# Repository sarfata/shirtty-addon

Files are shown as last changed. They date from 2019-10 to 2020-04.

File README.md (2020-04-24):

# shIRtty

A CircuitPython compatible, SAMD21 shitty addon with IR transmit/receive and RGB
LED.

## Bugs / Issues on v1.

**IMPORTANT** To make things more shitty the SAO header is upside down on the
badge. You will need a shitty inverser (included in this repo) or to put the
addon upside down. 

This is the pinout when looking at the face of the badge. Note that VCC is
bottom right (bottom left if you are looking at the connector).

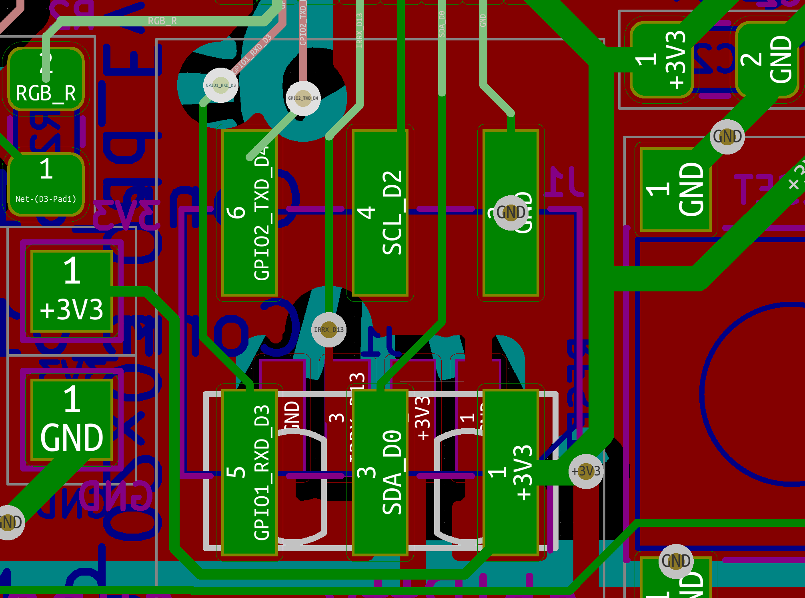
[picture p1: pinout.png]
pinout


### TODOs

- [ ] the SAO connector is upside down
- [ ] we need more capacitance on the +3V line otherwise we brown out when
    transmitting IR
- [ ] replace the very unreliable PCB usb connector by a micro usb connector
- [ ] make the reset button smaller so we can actually fit a SMD 6 pin SAO
    shrouded connector
- [ ] expose some GPIOs? 

## Micropython variant

### Build

Look at the readme in ports/atmel-samd.

```
# needed so gettext/msgfmt is available during build
export PATH="/usr/local/opt/gettext/bin:$PATH"

git clone git@github.com:adafruit/circuitpython.git
git submodule update --init --recursive
make -C mpy-cross

cd ports/atmel-samd

make BOARD=trinket_m0
(stopped there something funky going on where echo toto |xargs arm-none-eabi-gcc does not work)

```

## Bootloader

Some reference:

- https://forums.adafruit.com/viewtopic.php?f=57&t=142170&sid=a506885e77155bd9e062bbbab892efa3&start=15
- https://learn.adafruit.com/how-to-program-samd-bootloaders/itsybitsy-m0-m4-wiring

TODO:

- [x] Change the led configuration so they work on the RGB led we have on our board

### Build the bootloader

We only add two files from the adafruit version of the uf2 bootloader:

```
git clone git@github.com:adafruit/uf2-samdx1.git
```

`~/work/uf2-samdx1/boards/shirtty/board.mk`

```
CHIP_FAMILY = samd21
CHIP_VARIANT = SAMD21E18A
```

`uf2-samdx1/boards/shirtty/board_config.h`

```
#ifndef BOARD_CONFIG_H
#define BOARD_CONFIG_H

#define CRYSTALLESS 1

#define VENDOR_NAME "@sarfata"
#define PRODUCT_NAME "shIRtty"
#define VOLUME_LABEL "shIRtty"
#define INDEX_URL "https://github.com/sarfata/shirtty-addon"
#define BOARD_ID "shIRtty"

#define USB_VID 0x239A
#define USB_PID 0x001E

#define LED_PIN PIN_PA14

#endif
```

Then build with:

```
$ make BOARD=shirtty
```

I got an error at the end on a selfmain.c used for self update. #aintgottimeforthat - does not matter because the elf for the bootloader was built properly earlier.

### Using the Black Magic Probe

Connect:

- GND of the board to GND of BMP (use the SAO header)
- VCC of the board to VCC of BMP (use the SAO header)
- SWC/SWD/RST on the board to BMP (RST is optional - see below)

```
$ arm-none-eabi-gdb build/shirtty/bootloader-shirtty-v3.7.0-54-g63b4c6f.elf
(gdb) target extended-remote /dev/cu.usbmodem7AB17EC11

# If you need the black magic to provide power:
(gdb) monitor tpwr enable

(gdb) monitor swdp_scan
Target voltage: 3.3V
Available Targets:
No. Att Driver
 1      Atmel SAMD21E18A (rev D)
(gdb) attach 1

# if the bootloader is protected
(gdb) monitor unlock_bootprot

(gdb) load
(gdb) compare-sections

# if you want the new bootloader protected
(gdb) monitor lock_bootprot
```

Note: if you don't connect the RST line, you have to press reset after applying power, before running the `monitor` command. If the RST line is connected that is not needed.

### Unprotecting / Protecting the bootloader

First I had to update the firmware on my black magic probe (I had 1.6.1), I followed readme recommendations and installed daily build.

Version before:

    Black Magic Probe (Firmware 04d9749) (Hardware Version 3)

Upgrade with:

    sudo dfu-util -d 1d50:6018,:6017 -s 0x08002000:leave -D ~/Downloads/blackmagic-native.bin

Version after:

    Black Magic Probe (Firmware 04d9749) (Hardware Version 3)

Then the commands monitor unlock_bootprot becomes available.

Note: commands above do not work on the trinket m0 because the bootloader is protected. They should work on a fresh samd21e18 though.

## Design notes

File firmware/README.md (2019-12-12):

### How to setup a fresh ShIRtty.

1. Plug it into USB.
2. Copy all the files in `firmware/main` into the `CIRCUITPY` USB device.

### How to change the ShIRtty code.

1. Plug it into USB.
2. Open mu-editor
3. Load the code from `CIRCUITPY` USB device (`code.py` is the main file)
4. Save! (mu-editor should auto-update)

Pro-Tip: open the "Serial" window for a REPL and output.

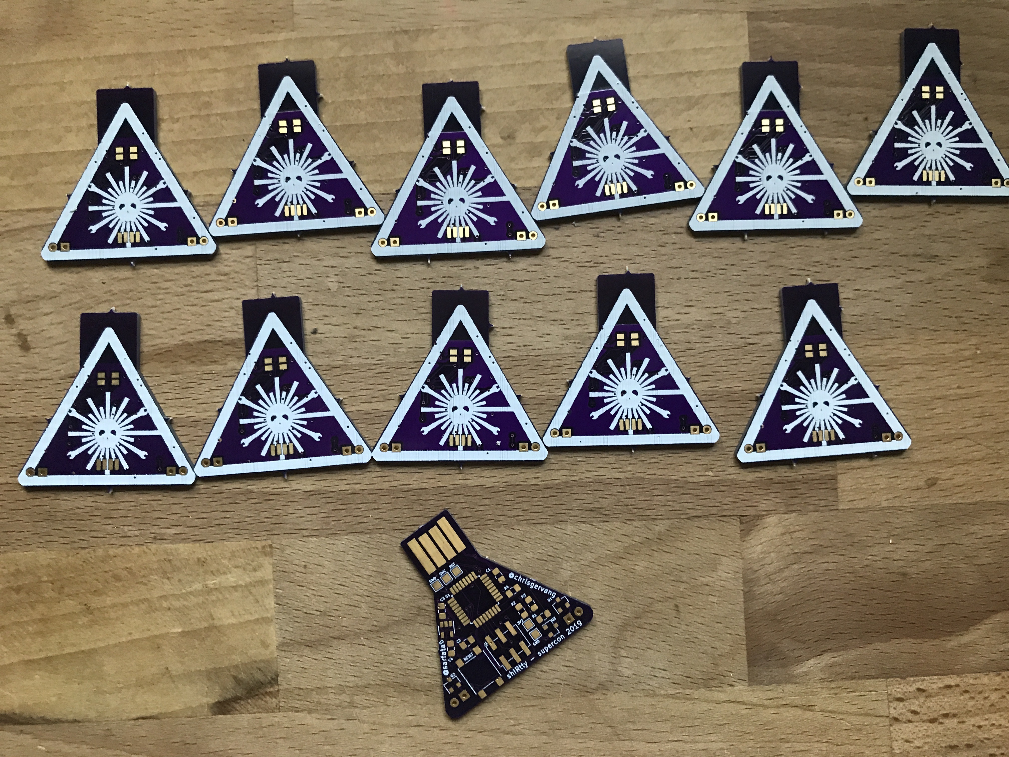
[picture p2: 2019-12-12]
photo.jpeg

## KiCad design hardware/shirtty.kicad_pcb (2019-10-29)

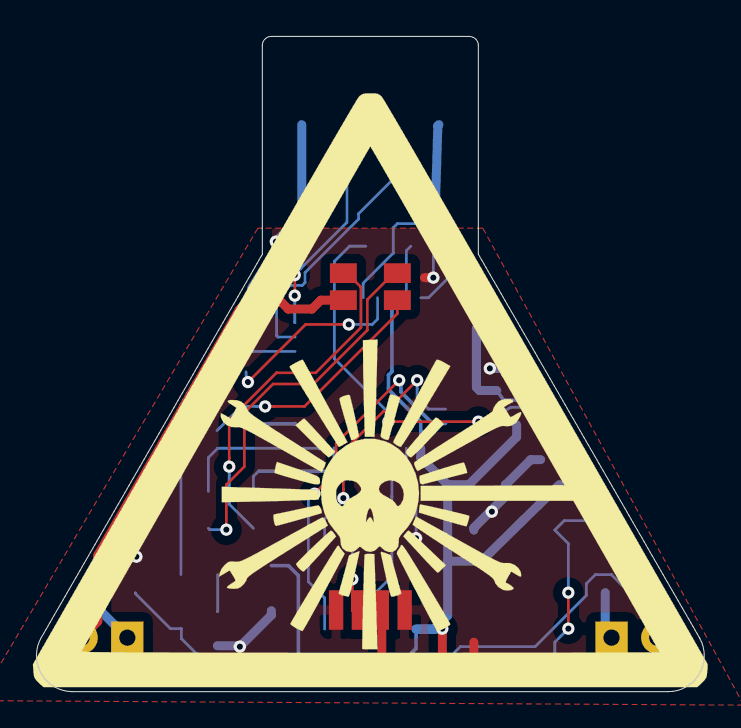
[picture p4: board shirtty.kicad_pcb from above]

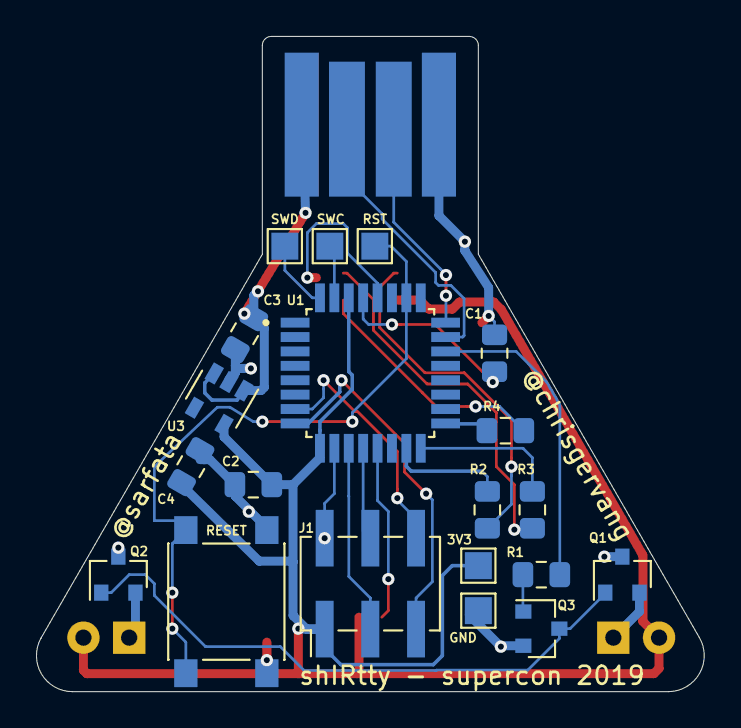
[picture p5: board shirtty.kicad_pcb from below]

Board: 2 copper layers, 37.1 x 36.4 mm, 25 parts (21 on the bottom side), 25 nets.

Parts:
3V3: Conn_01x01; TestPoint_Pad_1.5x1.5mm
C1, C2: 1uF; C_0805_2012Metric_Pad1.15x1.40mm_HandSolder
C3, C4: 10uF; C_0805_2012Metric_Pad1.15x1.40mm_HandSolder
D1, D2: LED; LED_D5.0mm
D3: LED_RGBA; LED_Avago_PLCC4_3.2x2.8mm_CW
GND: Conn_01x01; TestPoint_Pad_1.5x1.5mm
J1: Conn_02x03_Odd_Even; PinHeader_2x03_P2.54mm_Vertical_SMD
J2: USB_PCB; usb-PCB
Q1, Q2: Q_PNP_BEC; SOT-23
Q3: Q_NPN_BEC; SOT-23
R1, R2, R3, R4: 1k; R_0805_2012Metric_Pad1.15x1.40mm_HandSolder
RESET: SW_SPST; SW_Push_1P1T_NO_6x6mm_H9.5mm
RST: Conn_01x01; TestPoint_Pad_1.5x1.5mm
SWC: Conn_01x01; TestPoint_Pad_1.5x1.5mm
SWD: Conn_01x01; TestPoint_Pad_1.5x1.5mm
U1: ATSAMD21E18A-AF; QFP80P900X900X120-32N
U2: TSOP77438; TSOP774xx
U3: AP2112K-3.3; SOT-23-5

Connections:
+3V3: 3V3.1, C2.1, C4.1, D1.2, D2.2, D3.4, J1.1, U1.9, U1.30, U2.2, U3.5
/GPIO1_RXD_D3: J1.5, U1.8
/GPIO2_TXD_D4: J1.6, U1.7
/IRRX_D13: U1.13, U2.3
/IRTX: R1.2, U1.22
/RESET: RESET.2, RST.1, U1.26
/RGB_B: R4.2, U1.17
/RGB_G: R3.2, U1.16
/RGB_R: R2.2, U1.15
/SCL_D2: J1.4, U1.12
/SDA_D0: J1.3, U1.11
/SWCLK: SWC.1, U1.31
/SWDIO: SWD.1, U1.32
/USB_DM: J2.2, U1.23
/USB_DP: J2.3, U1.24
/VBUS: C3.1, J2.1, U3.1, U3.3
GND: C1.2, C2.2, C3.2, C4.2, GND.1, J1.2, J2.4, Q1.3, Q2.3, Q3.2, RESET.1, U1.10, U1.28, U2.1, U2.4, U3.2
unnamed: C1.1, U1.29
unnamed: D1.1, Q1.2
unnamed: D2.1, Q2.2
unnamed: D3.1, R2.1
unnamed: D3.2, R3.1
unnamed: D3.3, R4.1
unnamed: Q1.1, Q2.1, Q3.3
unnamed: Q3.1, R1.1

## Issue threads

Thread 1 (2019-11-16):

whups

siddacious, 2019-11-16:
https://fccid.io/RS4-E2281

sarfata, 2020-04-24:
👍 thx @siddacious ( Spring cleaning your github issues ?? 😜 )

Really cool fcc filing - there is even a schematic. I do not think the version we had with us has bluetooth but it's good to keep this archived!

cc @chrisgervang

Closed 2020-04-24.

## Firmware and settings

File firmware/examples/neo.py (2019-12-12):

from pixels import ShittyPixels
shit_pixels = ShittyPixels()
shit_pixels.on()
pixels_start_hue = 0

 # elif code_match == Codes.adafruit.ADAFRUIT_3:
    # shit_pixels.toggle()


while True:
    # pixels
    if shit_pixels.is_on():
        for i in range(0, 64, 1):
            row = round(i / 8)
            column = i % 8
            hue = (pixels_start_hue + row / 3 + column / 5) % 6

            rgb = hsl_to_rgb(hue, 1, 0.02)
            shit_pixels.pixels[i] = (round(rgb[0]*255), round(rgb[1]*255), round(rgb[2]*255))

        shit_pixels.pixels.show()
        pixels_start_hue = pixels_start_hue + .3

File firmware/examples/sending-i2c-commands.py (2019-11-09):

# Write your code here :-)
import board
import busio
import random
import time

i2c = busio.I2C(board.SCL, board.SDA)

while not i2c.try_lock():
    print("trying to lock bus...")



while True:
    hue = round(random.random() * 255)
    print("Asking for color {}".format(hue))
    i2c.writeto(0x42, bytes([hue]))

    print("sleeping...")
    time.sleep(5)

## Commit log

2019-10-29 initial commit of hardware
    [shirtty.kicad_pcb, shirtty.sch]
2019-11-06 add shitty-inverser
    [shitty-inverser.kicad_pcb, shitty-inverser.sch]
2019-11-09 feature: route inverser so it works without metallized hole
    [shitty-inverser.kicad_pcb]
2019-11-16 Updating Friday night fixes. Power remote to turn off!
